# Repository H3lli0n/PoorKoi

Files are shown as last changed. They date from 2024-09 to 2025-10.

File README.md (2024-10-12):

### HLB PoorKoi is a 60% stacked acrylic keyboard

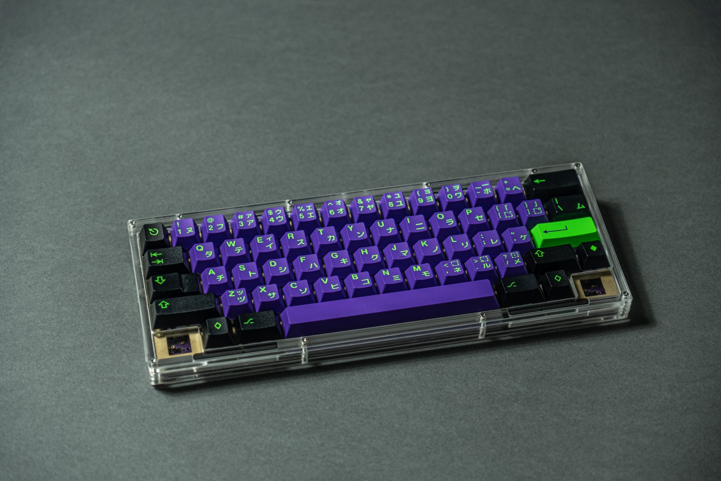
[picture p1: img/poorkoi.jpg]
Prototype


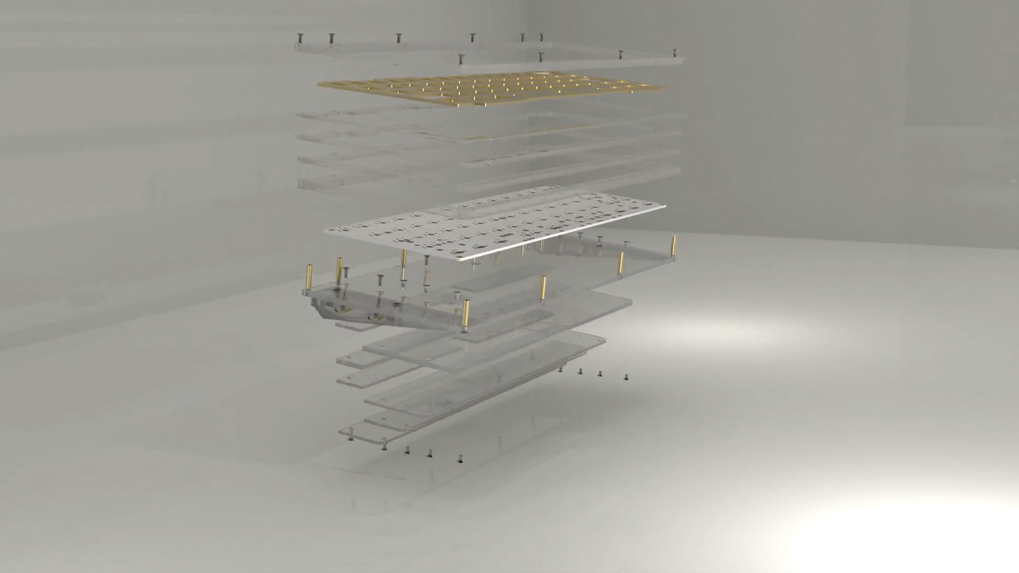
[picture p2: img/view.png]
Stack


# Why PoorKoi

Well it's a funny joke between a poor version of a well known 60% keyboard kit with a kohaku and also a wordplay with _Pourquoi_ a french word meaning _Why_

# Where can I buy one ?

Unfortunately PoorKoi was a private group-buy on Deltakeyco.com from July 1st to July 15th 2024.
At this time we don't share drawings of acrylic layers but plate STEP file is available.

# What can I find here ?

Here you'll find the build guide as well as the firmware for pcb. It's based on 4pplet pcb with a custom look and source code is available to match the open source license.
Firmware is matching our layout as well as options such as:
- Split backspace
- Split left shift
- Iso Enter
- Split spacebar
- WK/WKL/HHKB layout
- RGB underglow
- Capslock LED support

# Layouts

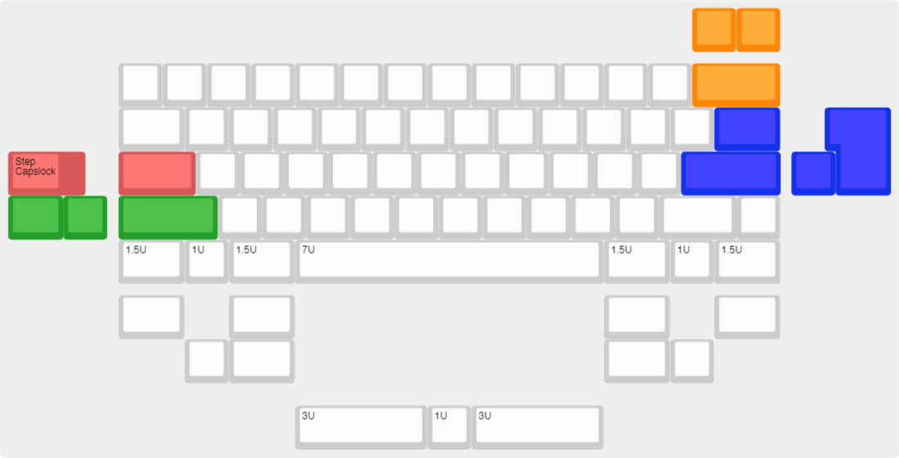
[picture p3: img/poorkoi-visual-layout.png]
Supported_layouts


# Release notes after production

* 2024/10/12 notes about upcoming free fixes [fixes note](notes/october2024/october20241012.md)
* 2024/10/07 listing the issues and upcoming free replacement parts [release note](notes/october2024/october20241007.md)

# Special note / Disclaimer

PCB underglow was not described in the GB and we were keeping it as a secret. After the GB, 5 people requested and extra PCB in purple and this batch was ordered with the same production file. Those 5 pcb arrived before the white ones and everything was fine.

When Deltakeyco received the white PCB we discovered underglow LED were missing. As 5 people would be able to  make pictures with underglow we decided to buy and include the missing LED in the package.

You're free to solder or ask someone to solder. Be advised this process is not so easy as parts are very tiny. Please take time to ask or watch video how to properly solder those components ! 

Ok now you are well aware of the risks, you can follow for example this documentation : [How to Solder SMD / SMT Components](https://www.instructables.com/How-to-Solder-SMD-SMT-Components-With-a-Soldering-/)
On the PCB you will find 16 spots like this one 

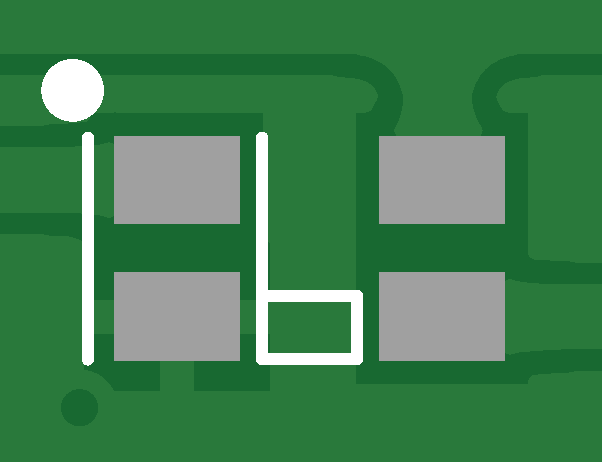
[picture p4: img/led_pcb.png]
PCB led footprint


As you can see there is a dot and vertical line giving you the correct side for the SMD led component. When you flip it the green line must be on the same side as the dot

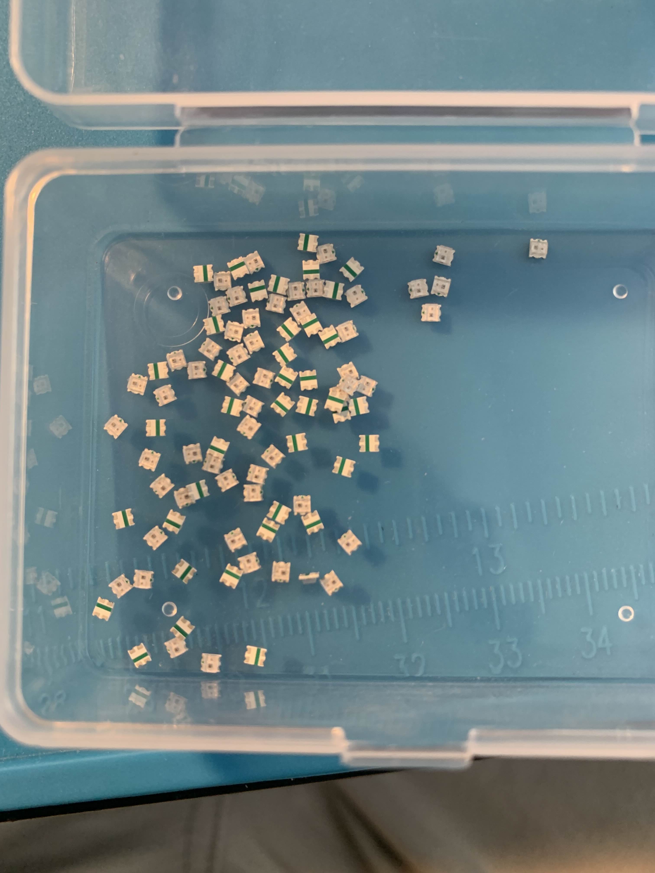
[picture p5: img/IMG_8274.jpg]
SMD


# So what's next ?

Next HLB's project is a TKL made of aluminum with CNC machining. It will be more expensive but others _Poor_ projects will come next.
Follow us on discord for more information here: https://discord.gg/pehBKyyYYs

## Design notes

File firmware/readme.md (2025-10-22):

# Vial Firmware

- This folder contains the latest VIAL firmware

[PoorKoi latest firmware](https://github.com/H3lli0n/vial-qmk/releases?q=poorkoi&expanded=true)

# How-to flash

Simply use the old and well known QMK Toolbox. Use desktop version of VIAL to backup ad restore your layouts.

# Source code

- Source code is available through my fork [here](https://github.com/H3lli0n/vial-qmk/tree/HLB_PoorKoi)
- The reset button on pcb is located here and can be activated with tweezers
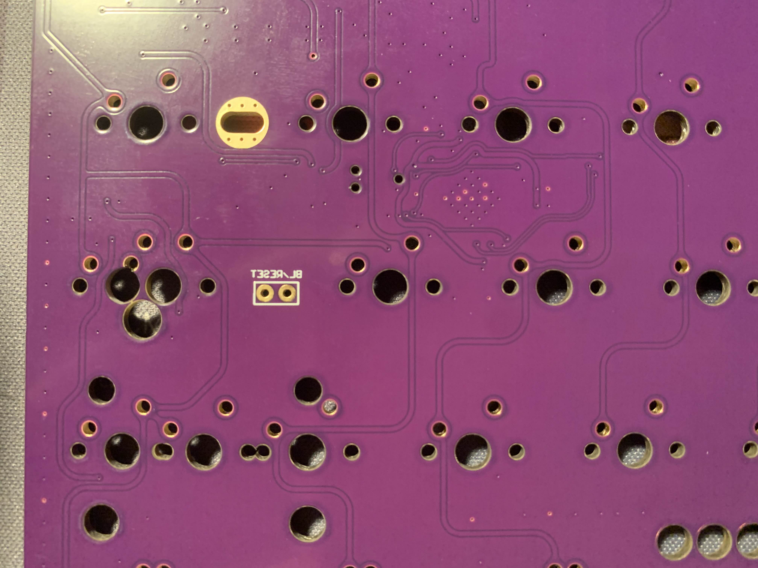
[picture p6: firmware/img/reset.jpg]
Reset


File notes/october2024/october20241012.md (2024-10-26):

# Mise en place du sav

Le sav est en cours de production et est attendu pour la fin du mois.<br>
**Pour rappel, les pièces acryliques et la plate en laiton sont à la charge de HLB et donc gracieusement offertes**.<br>
Nous demandons seulement de regrouper si possible votre SAV avec une autre commande prévue chez DKC ou bien avec un copain de PoorKoi.

Sont donc à votre charge les quelques fournitures de visserie évoquées plus bas.

Concernant les corrections nous avons donc:
* La correction du trou de fixation des pieds
* Diminution du fraisage pour les vis qui maintiennent la daughterboard
* Eléments de remplacement pour la fixation de la daughterboard
* La plate en laiton revision 2 pour la configuration ISO et/ou les personnes ayant des difficultés à insérer les switches  (taille de 14mm x 14mm au lieu de 13,9mm x 13,9mm)
* Un jst avec les fils dans le bon ordre (si il y a eu casse ou impossibilité de changer l'ordre)
* Des patins en feutrine de 1.5mm pour remplacer ceux en matière plastique qui ne sont pas pratiques

# Plate

Si vous décidez de changer de plate, il vous faut de nouveaux gaskets car le poron est difficile à décoller et peut s'arracher. Voici ceux qui vous ont été livrés:
* https://fr.aliexpress.com/item/1005005171752968.html
  * Choisir 90x4x3mm white

A date le produit est out of stock. Je vous indique un lien alternatif mais trop cher :-(
* https://fr.aliexpress.com/item/1005007081069765.html
  * Choisir 90x4x3mm white

Une autre solution est d'acheter ce rouleau multi-usages EVA et de découper vos gaskets dedans
* https://fr.aliexpress.com/item/1005005057632486.html
  * Choisir épaisseur 3mm mais la matière est plus dense que le poron et donc moins compressible. En ce sens je privilégierai donc le 2mm ce qui peut également apporter un peu de flex général.

A noter que le EVA isole mieux que le poron, avec 2mm on a donc une meilleure absorption des ondes et potentiellement du flex. Sous réserve d'expérimentation.

# Fixation de la daughterboard

Pour résoudre les problèmes de la fixation de la daughterboard, je vous propose 3 solutions.
Voici les liens vers les fournitures des solutions:
* https://fr.aliexpress.com/item/1005006049595637.html	
  * Choisir M2 x 3mm
* https://fr.aliexpress.com/item/1005005974779771.html	
  * Choisir M2 x 3mm
* https://fr.aliexpress.com/item/1005003323071003.html	
  * Choisir M2 white

## Scénario 1 : taux de réussite 60%

* Réutiliser la visserie existante
* Utiliser la petite plaque de 2mm en dessous de la daughterboard
* Utiliser les oring pour compenser le 1 à 2mm perdu sur le pas de vis

Voici une illustration
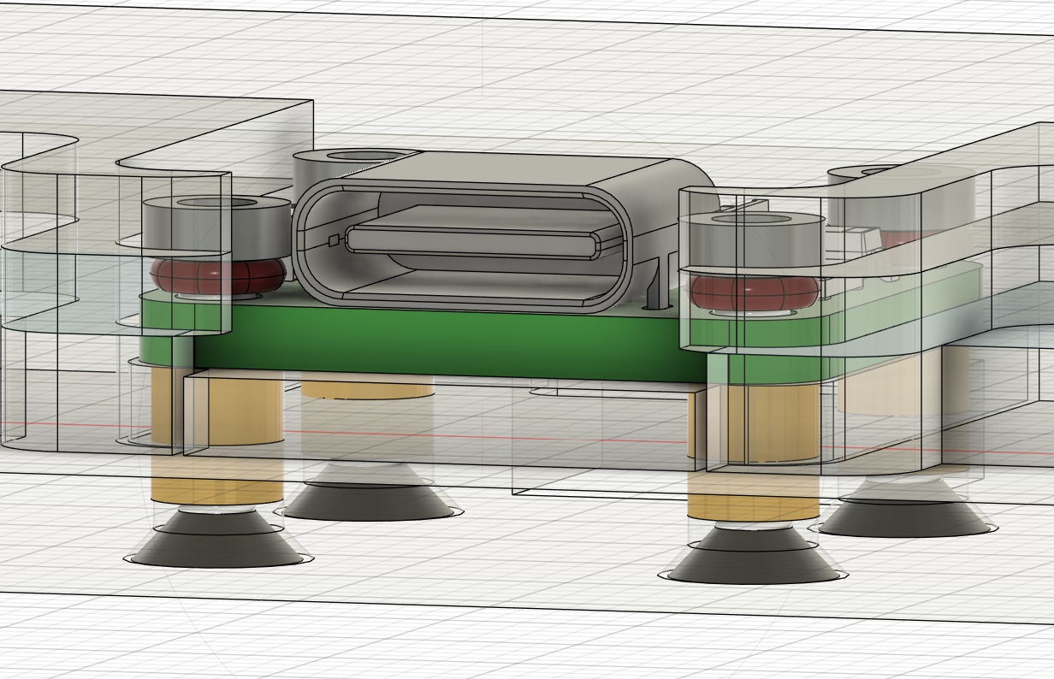
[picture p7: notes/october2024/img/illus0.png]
Scénario 1


## Scénario 2 : taux de réussite 80%
* Utiliser les vis fraisées M2 x 3mm commandées
* Réutiliser les entretoises 4mm
* Utiliser la plaque de 2mm en dessous de la daughterboard

La db ne sera pas plaquée sur le plaque avec les résidus de soudure en dessous, les vis de 3mm sont adaptées et en serrant des 2 côtés la prise de filet sera homogène.

Voici une illustration
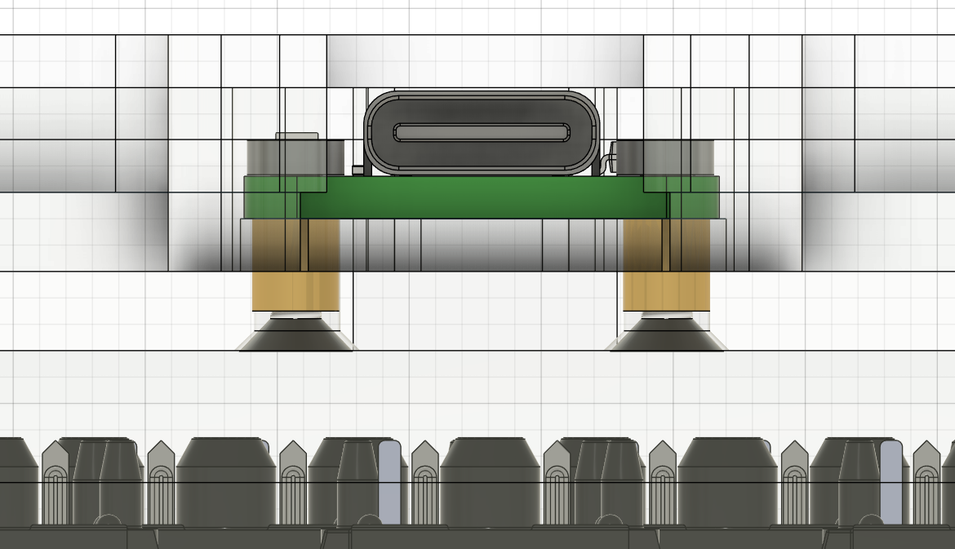
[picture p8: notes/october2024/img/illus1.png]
Scénario 2a

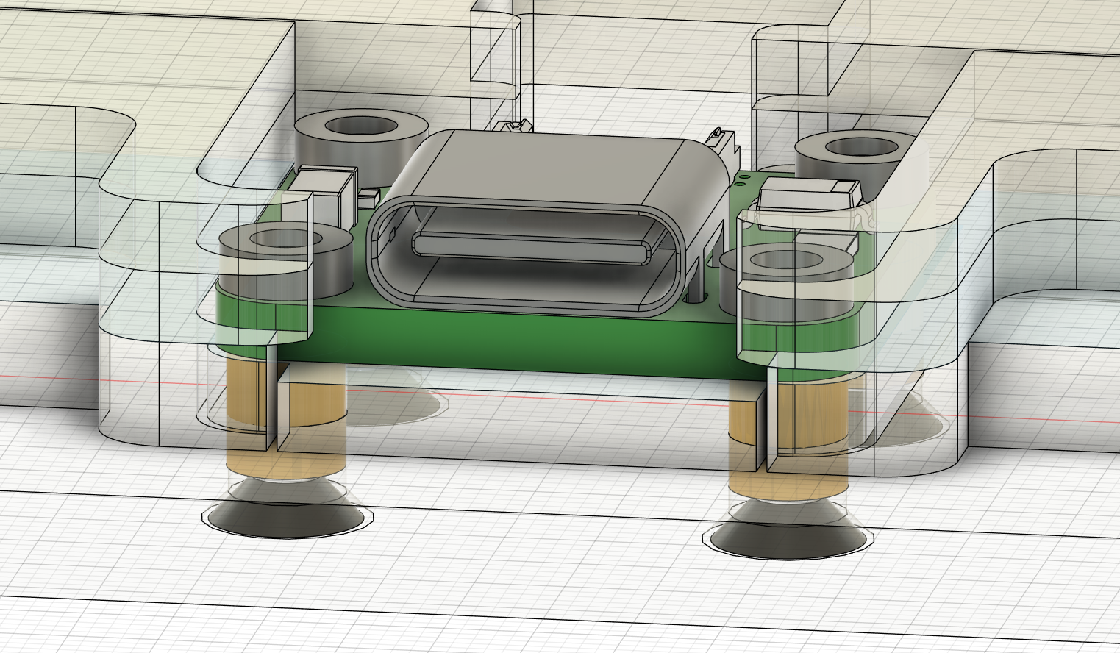
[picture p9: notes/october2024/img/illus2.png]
Scénario 2b


## Scénario 3 : taux de réussite 99% :-)

Ce scénario revient à la configuration du proto. Lors du montage il a été noté que manipuler les vis de 3mm avec une entretoise de 3mm était compliqué et que la prise de filet devait être précise.
Néanmoins la daughterboard était correctement positionnée et ne bouge pas.

Pour reprendre le design original tout en ayant une marge de manoeuvre sur la prise de filet, j'ai donc demander la réalisation d'une plaque de 1mm qui va permettre de combler les écarts.

Ce scénario offre aussi le meilleur espacement entre le haut du port usb et la plaque couvrante, nous aurions dû conserver ce design.

* Utiliser les entretoises M2 x 3mm
* Utiliser les vis fraisées M2 x 3mm
* Utilliser la plaque de 1mm sous la daughterboard si nécessaire ou les oring

Voici une illustration
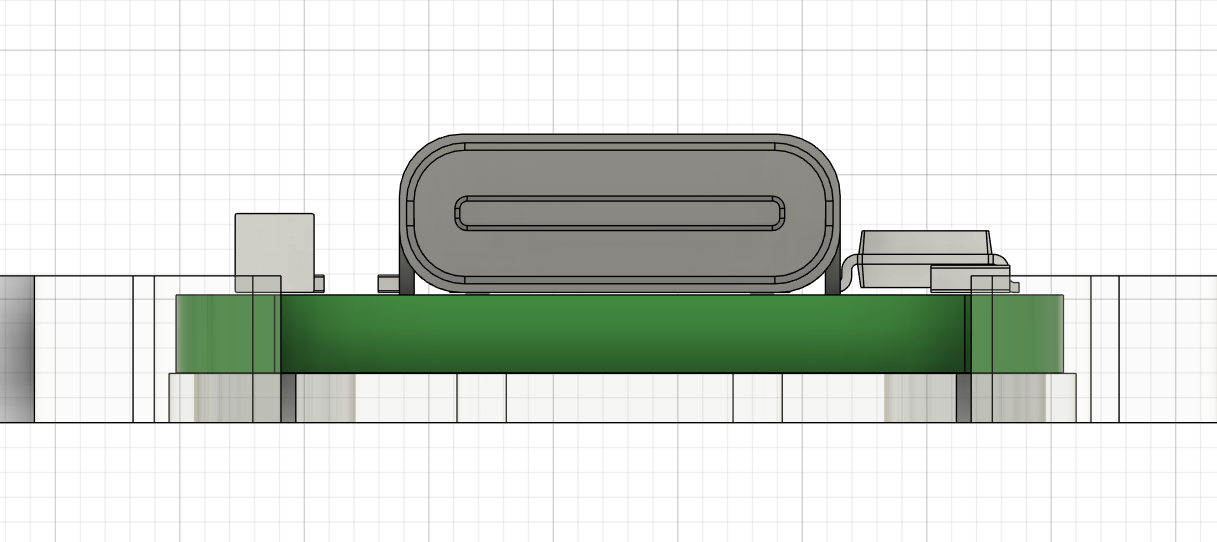
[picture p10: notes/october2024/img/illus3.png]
Scénario 3a

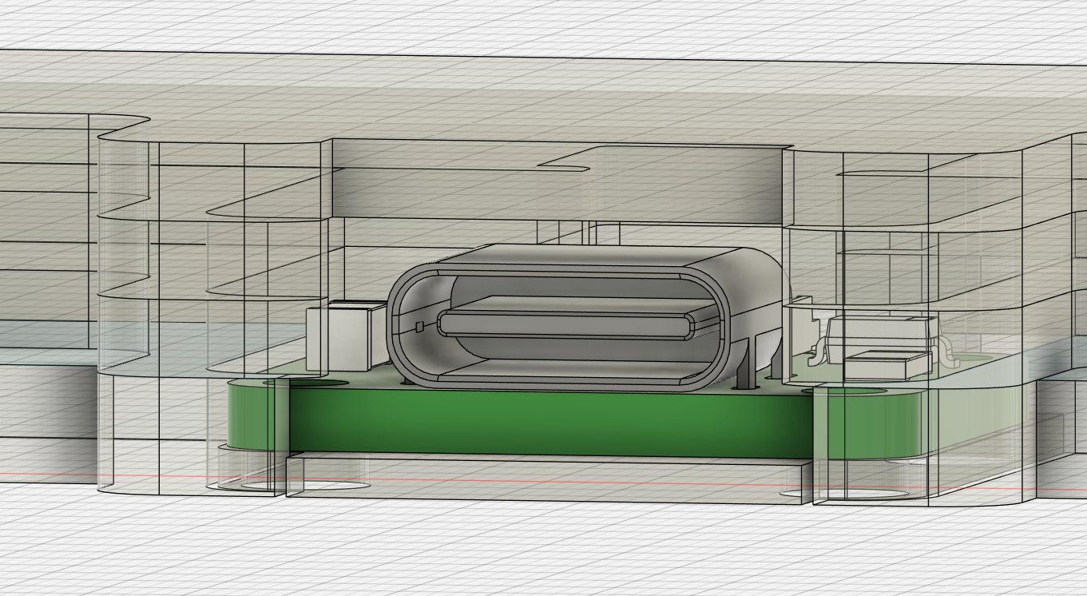
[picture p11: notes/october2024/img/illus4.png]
Scénario 3b


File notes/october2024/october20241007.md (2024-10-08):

# Note sur la production au 7/10/2024

Suite aux livraisons et build du PoorKoi, des problèmes ont été rencontrés à différents niveaux. HLB est désolé de la situation, nous ne pensions pas avoir autant de soucis sur la fin de production.

Tout d'abord je vous informe que nous avons pris l'ensemble des problèmes sérieusement et assumons le SAV. Ainsi, nous avons maintenant la vision d'ensemble des soucis et lançons la mise en production dès que possible du SAV (nous sortons d'une période de vacances en Chine il y a donc du délais).

## Fixation des pieds

Un trou de fixation n'est pas axé avec la plaque principale possédant le Koi:
* modification suite au prototype
* le dessin a été mis à jour
* la plaque va être commandée pour 30 unités

## Port USB

* modification suite au prototype pour éviter de manipuler de la visserie 3mm
* effet de bord sur l'espacement avec le port usb
* erreur humaine lors des vérifications
* retour arrière sur la fixation de la daughterboard sur la base du prototype

### Avant

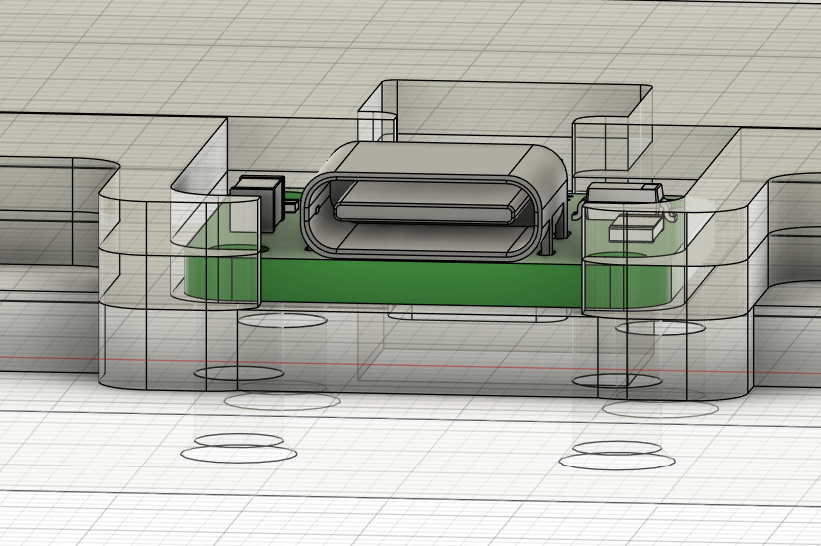
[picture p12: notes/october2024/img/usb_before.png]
Avant


### Après 

Fix en cours (peut changer)

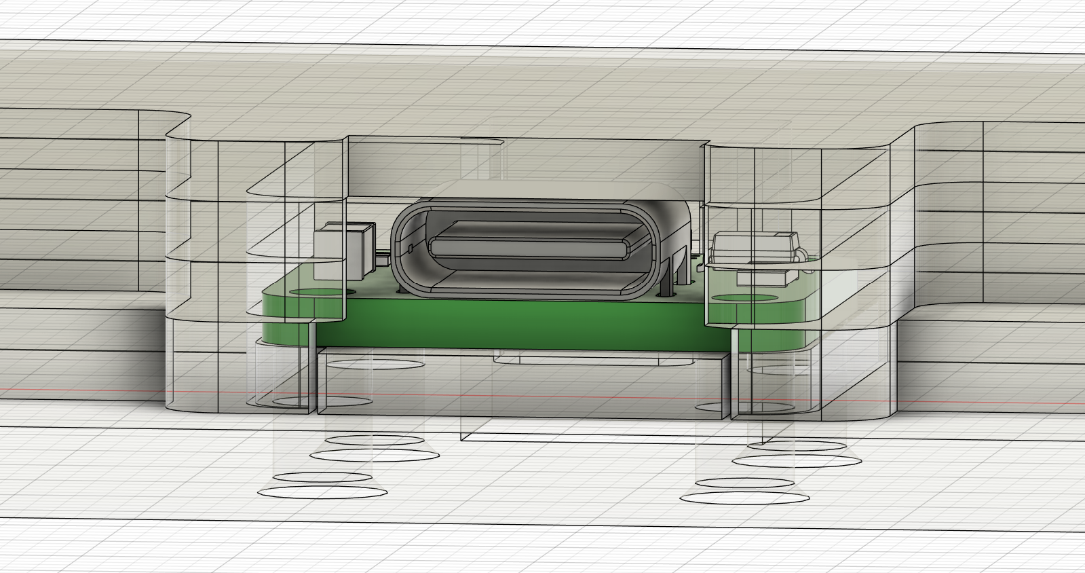
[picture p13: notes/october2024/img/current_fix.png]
Après


note: une communication sera réalisée sur la visserie à utiliser

## JST to molex

Comme expliqué sur le discord, la connexion initiale était JST-JST mais suite à une erreur de fichier lors de la production chez JLC, nous avons livrer des daughterboard JST-Molex et avons par conséquent commandé les câbles nécessaires avec le schéma technique officiel.

Les câbles sont arrivés avec un connecteur inversé et sommes en conversation avec l'entreprise, pour qui la production reflète le dessin; ce qui est faux.
A ce jour je suis toujours en «litige» avec eux mais vous pouvez inverser vous-même les fils (venez sur le discord pour un tuto).

=> en attente réponse entreprise

## Plate pour le ISO

Une erreur est apparue chez les utilisateurs ISO, une découpe est manquante pour le switch situé à côté du Enter ISO.
* erreur humaine lors de la mise en forme de la plate
* une plate de remplacement va être commandée pour les 30 unités et fournie dans le carton
* nous allong également mettre les emplacements de switchs en 14mm et non en 13.9mm suite à des remontées sur des switchs trop serrés

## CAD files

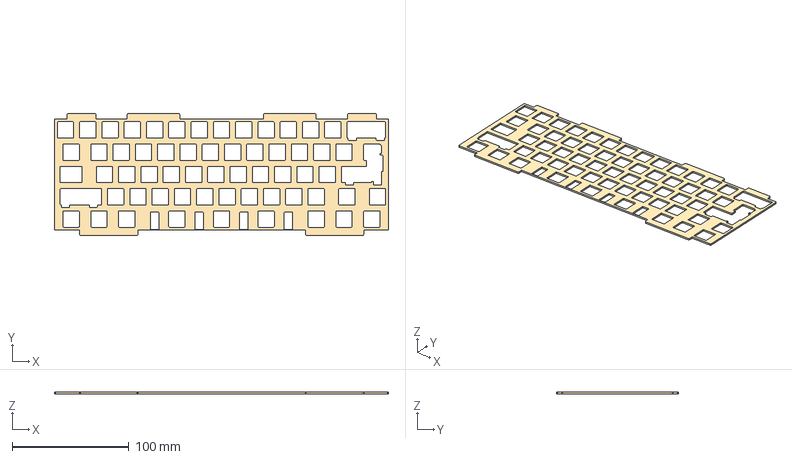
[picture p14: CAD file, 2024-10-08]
production_files/plate_rev3.step
285.6 x 104.3 x 1.50 mm

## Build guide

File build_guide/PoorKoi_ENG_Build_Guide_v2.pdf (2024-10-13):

# PoorKoi

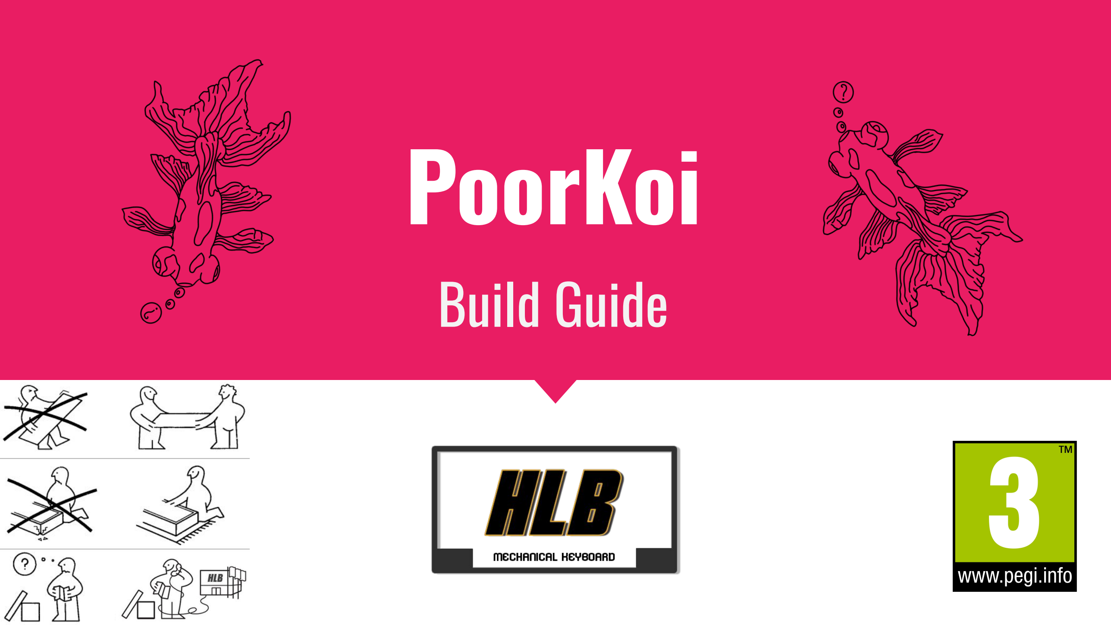
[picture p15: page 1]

# Build Guide

# Step 0 : kit content

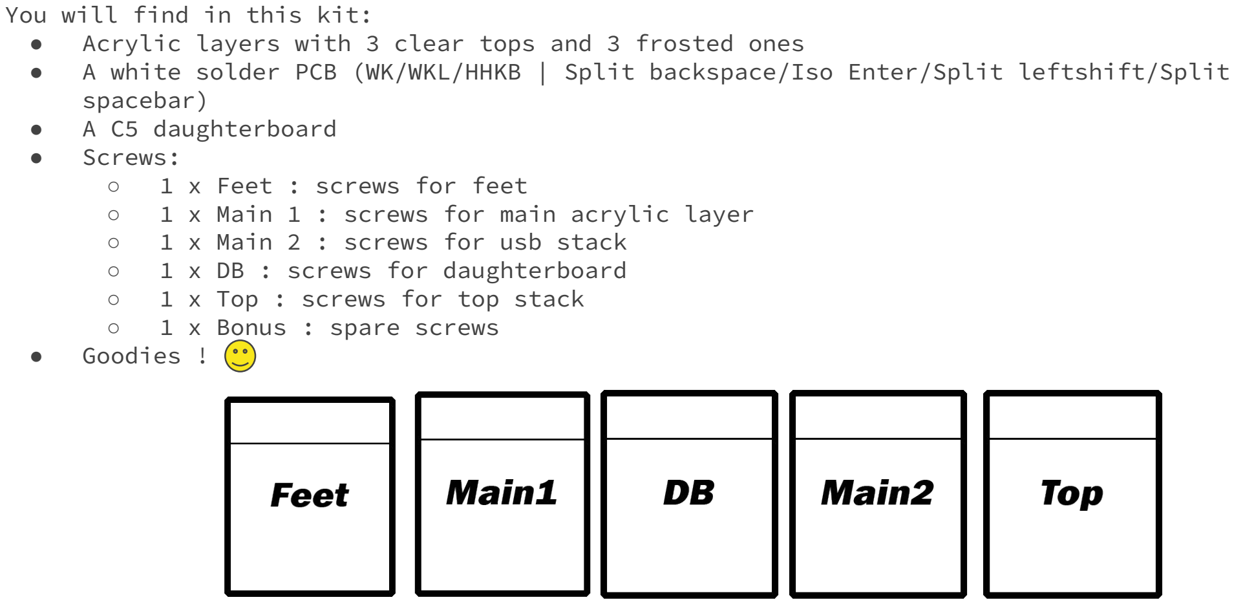
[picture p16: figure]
You will find in this kit:; spacebar) ● A C5 daughterboard ● Screws: ○ 1 x Feet : screws for feet; ○ 1 x Main 2 : screws for usb stack ○ 1 x DB : screws for daughterboard ○ 1 x Top : screws for top stack ○ 1 x Bonus : spare screws ● Goodies !

- Acrylic layers with 3 clear tops and 3 frosted ones
- A white solder PCB (WK/WKL/HHKB | Split backspace/Iso Enter/Split leftshift/Split
- 1 x Main 1 : screws for main acrylic layer

# Step 0 : content

Kit is full of surprises with 24 simple configurations mixing frosted and clear parts. In white all the parts available in both variants.

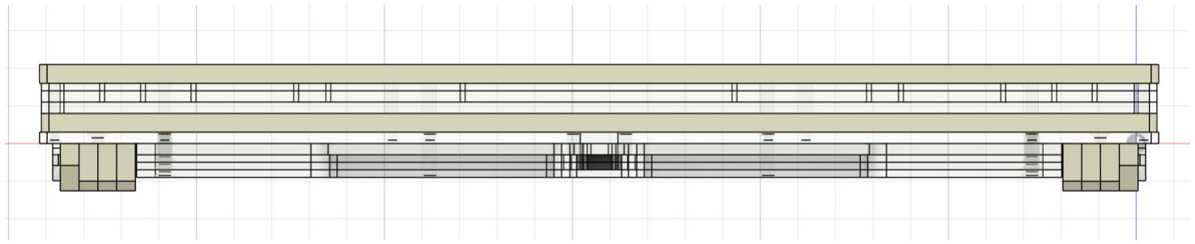
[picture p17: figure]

-tops
-5mm acrylic layer on top of Koi’s one -5mm pieces of feet

# Step 1 : qmk toolbox installation

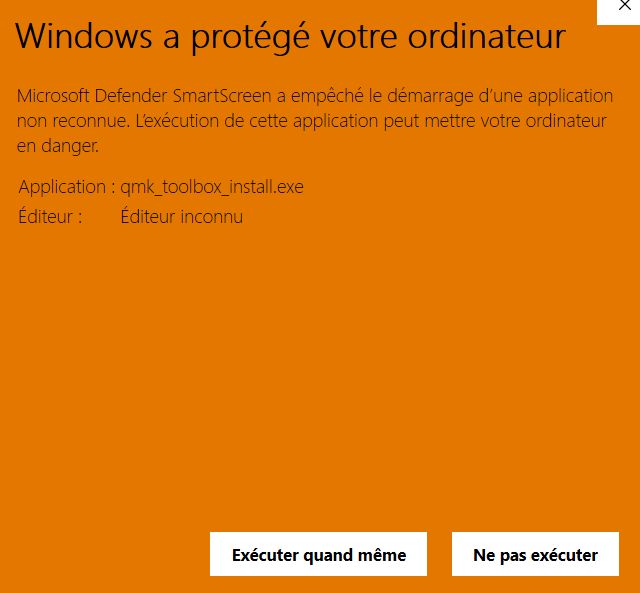
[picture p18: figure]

- PCB is empty of firmware, you will learn if not how to flash your PCB. Easy step no worries !
- Download QMK Toolbox here: https://github.com/qmk/qmk_toolbox/releases/download/0.3.3/qmk_toolbox_install.exe (https://github.com/qmk/qmk_toolbox/releases/download/0.3.3/qmk_toolbox_install.exe) (latest version at the time of writing)
- You can trust the installer, the warning is related to missing certificate
- Once installed, please launch as administrator
- Click on Tools\Install drivers and wait the console closing by itself

# Step 1 : firmware flashing

1

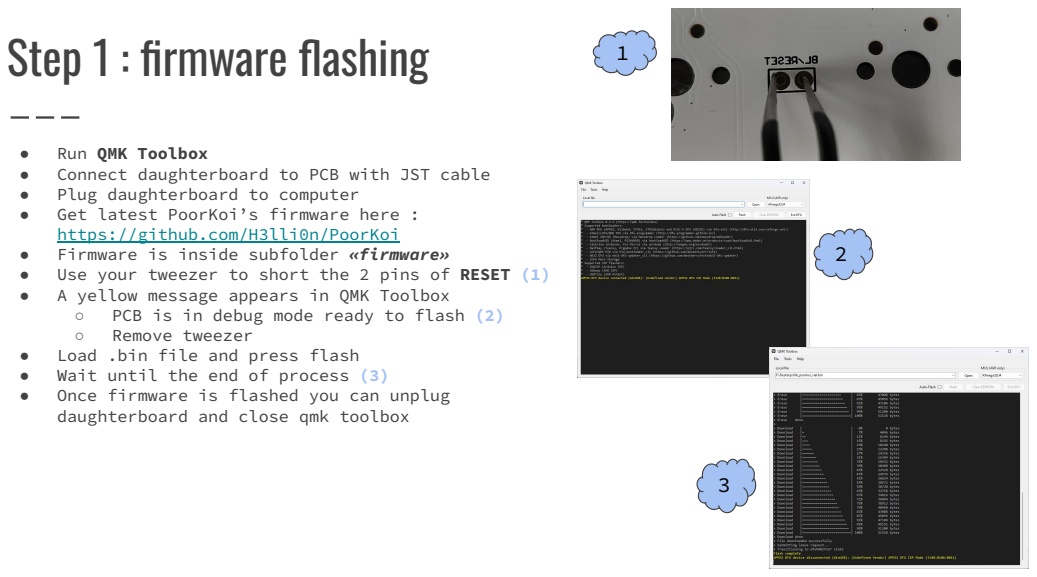
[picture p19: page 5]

● Run QMK Toolbox
● Connect daughterboard to PCB with JST cable
● Plug daughterboard to computer
● Get latest PoorKoi’s firmware here :
https://github.com/H3lli0n/PoorKoi
● Firmware is inside subfolder «firmware»
● Use your tweezer to short the 2 pins of RESET (1)
● A yellow message appears in QMK Toolbox
○ PCB is in debug mode ready to flash (2)
○ Remove tweezer
● Load .bin file and press flash
● Wait until the end of process (3)
● Once firmware is flashed you can unplug
daughterboard and close qmk toolbox

# Step 2 : check PCB

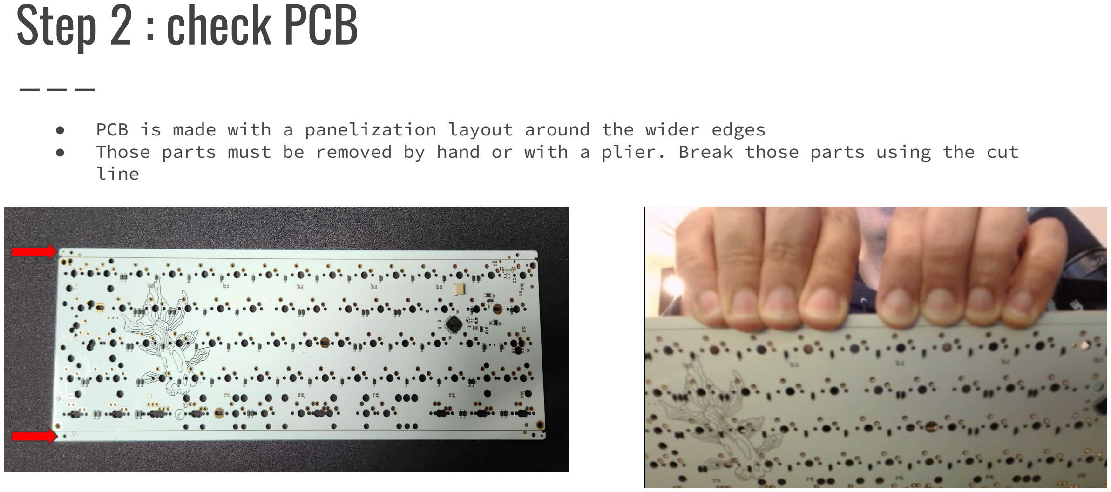
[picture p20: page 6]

- PCB is made with a panelization layout around the wider edges
- Those parts must be removed by hand or with a plier. Break those parts using the cut line

# Step 2 : check PCB

- | To test PCB we will use | https://config.qmk.fm/#/test | because VIAL requires to unlock
PCB and without switches it’s a dual tweezers process
- Plug daughterboard
- User your tweezer to test each switch contact holes. Everyone must answer except MO(1) located at the right of right shift
- Once PCB is checked you’re free to solder or mill-max your PCB
- PCB supports underglow RGB but due to some issue during order, you have to solder the led included in the kit. Please read carefully the disclaimer on the main git
| repo webpage.
- Lube and test your stabilizers
- Insert switches on the plate and clip on PCB
- PCB supports caps lock LED think about it before soldering !
- Solder your switches if required

# Step 3 : feet

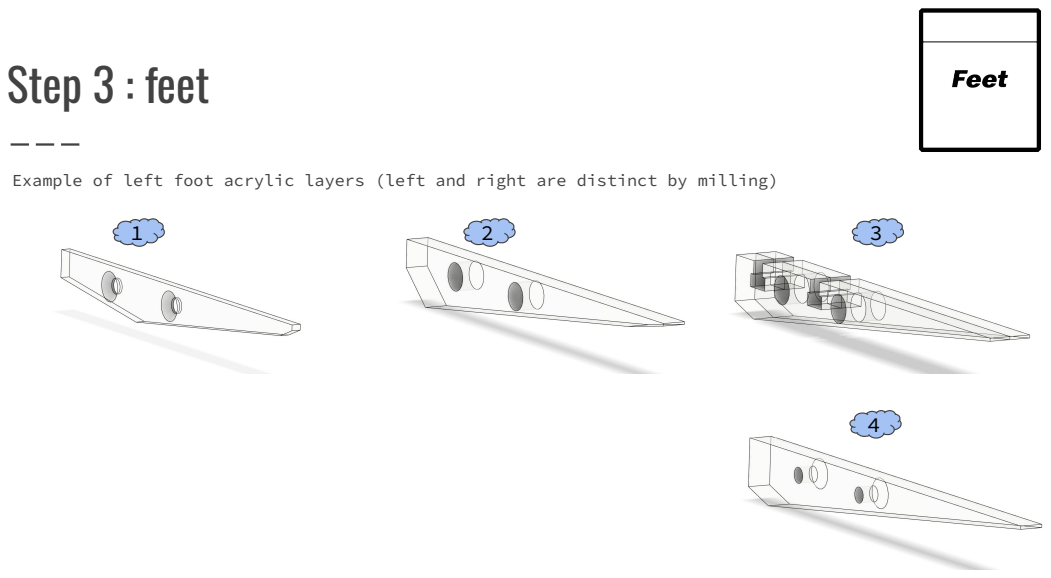
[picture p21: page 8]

Example of left foot acrylic layers (left and right are distinct by milling)

# Step 3 : feet

## Insert

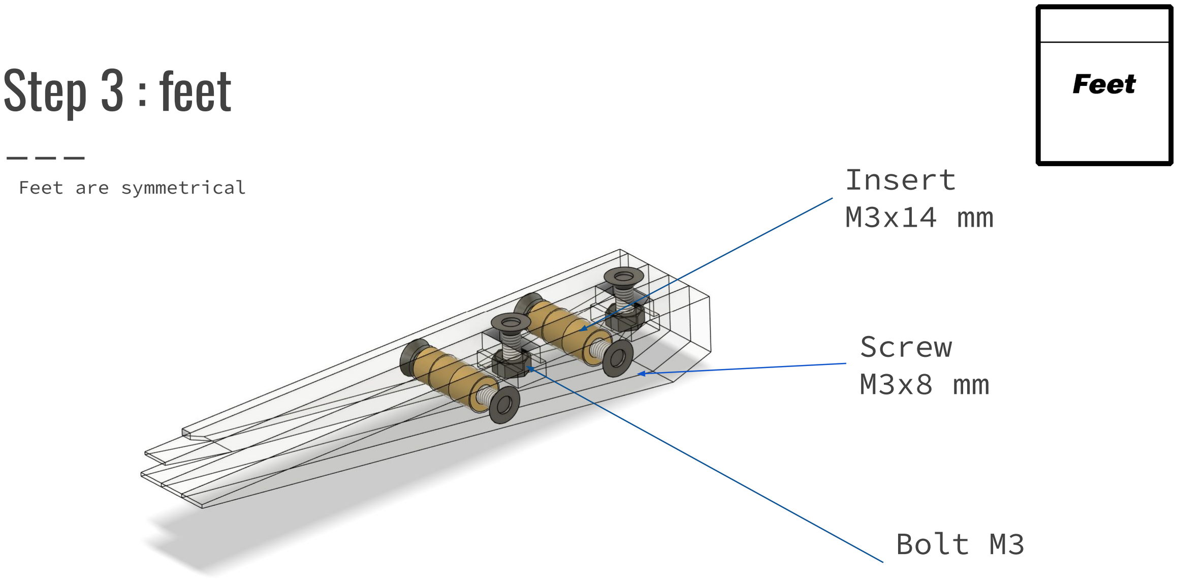
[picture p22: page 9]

## M3x14 mm

## Screw M3x8 mm

## Bolt M3

Feet are symmetrical

# Step 3 : feet

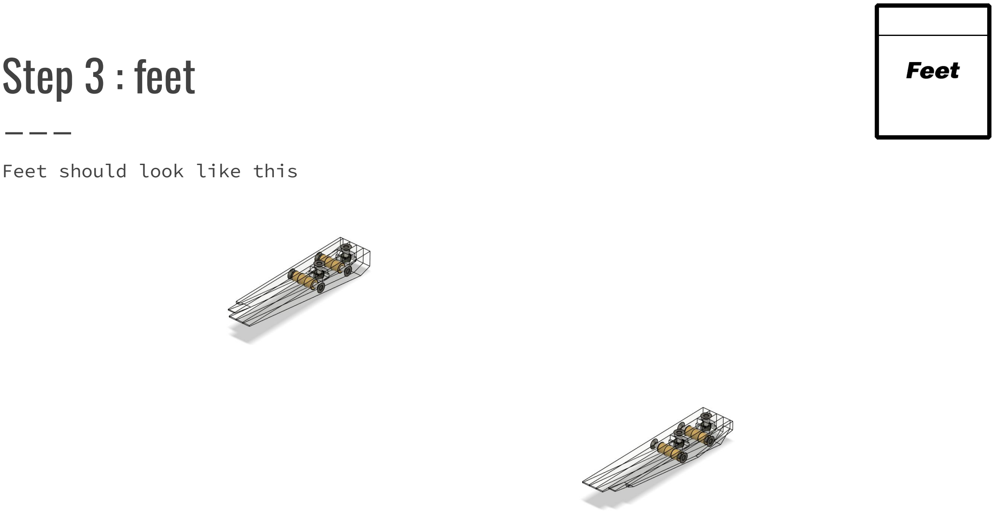
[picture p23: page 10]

Feet should look like this

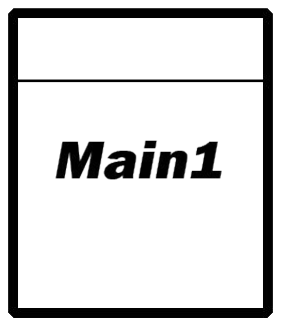
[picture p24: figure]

# Step 4 : bottom stack

- Use Chicago screws head down
- Put the main acrylic layer with koi fish
- Use picture on next page
- Put the other 3 acrylic layers to match next picture

# Step 4 : bottom stack

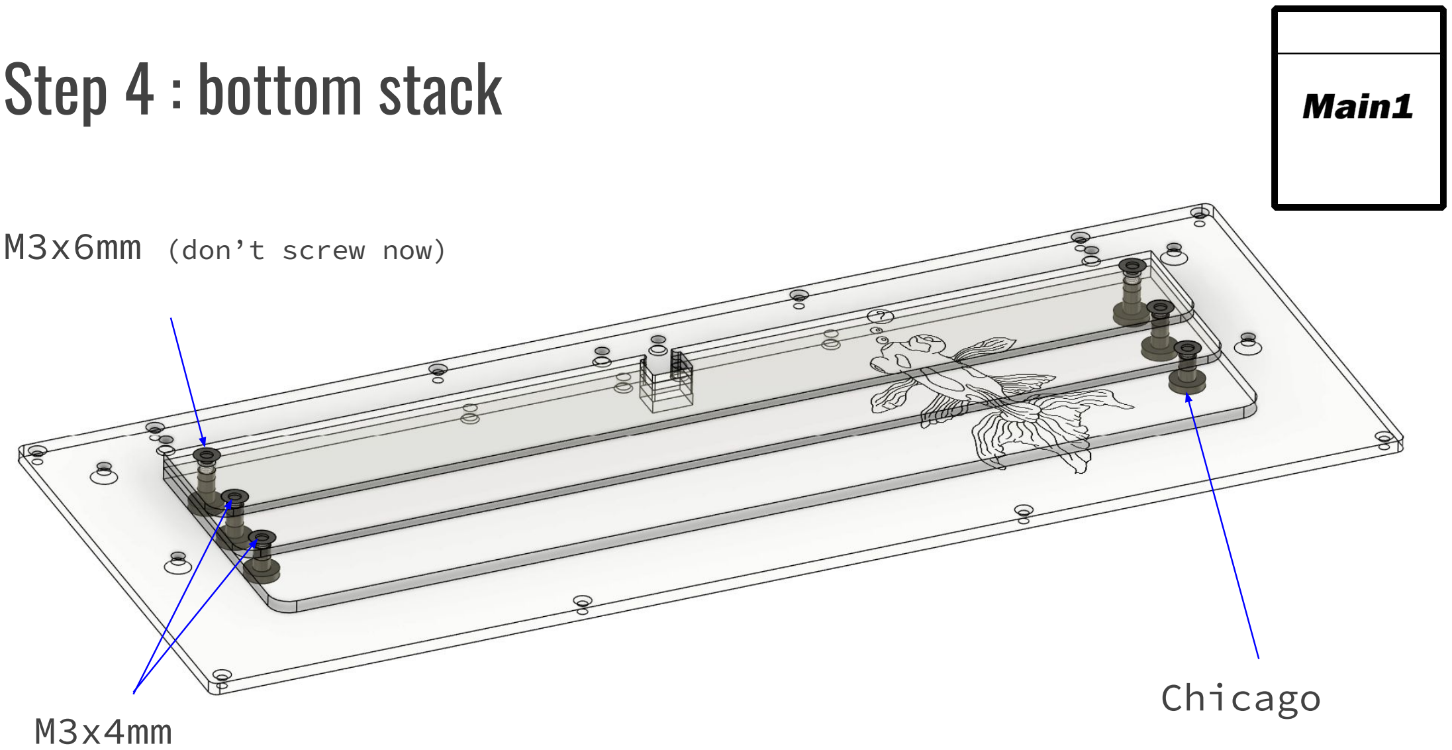
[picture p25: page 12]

## Chicago

M3x6mm (don’t screw now)

## M3x4mm

# Step 4 : bottom stack

- Plug JST cable to daughterboard
- Insert JST through the main acrylic layer

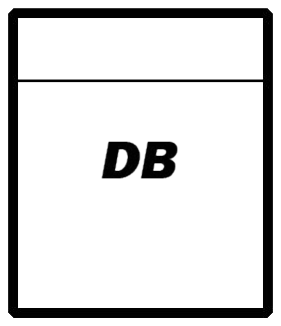
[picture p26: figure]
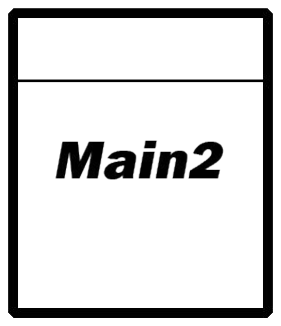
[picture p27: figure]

- Setup countersunk M2 screws and insert and put them on table, screw head down. Insert acrylic layers
- Use M2x3mm screws to secure daughterboard
- Stack halves acrylic layers around the daughterboard and final layer as shown on next picture
- Screw everything to secure bottom stack

# Step 4 : assembler la stack

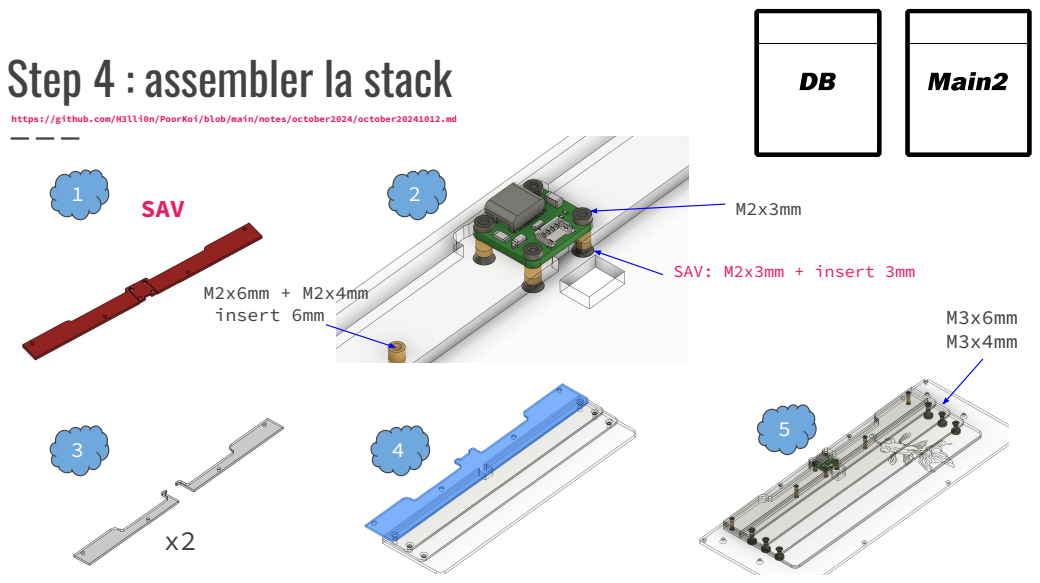
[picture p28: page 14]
SAV; SAV: M2x3mm + insert 3mm; insert 6mm

https://github.com/H3lli0n/PoorKoi/blob/main/notes/october2024/october20241012.md

# Step 5 : feet assembly

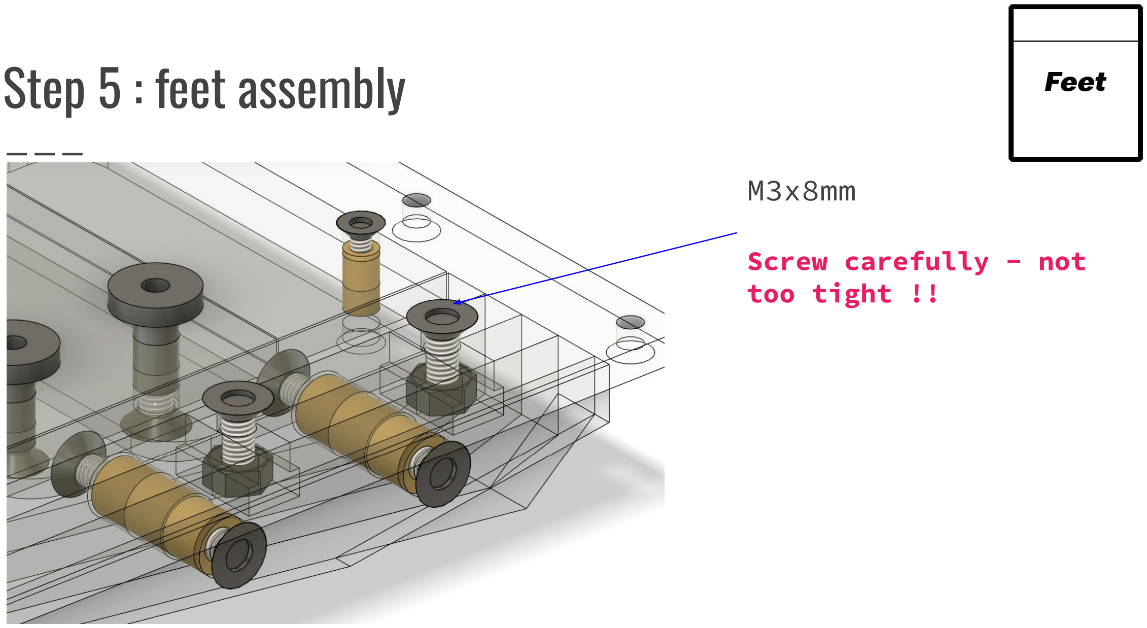
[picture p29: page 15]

## M3x8mm

## Screw carefully - not too tight !!

# Step 6 : gaskets

## Gaskets sizes are :

## - Top : 25 mm / 45 mm / 45 mm / 25 mm - Bottom : 50mm / 50 mm

## Just install gaskets on plate on both sides

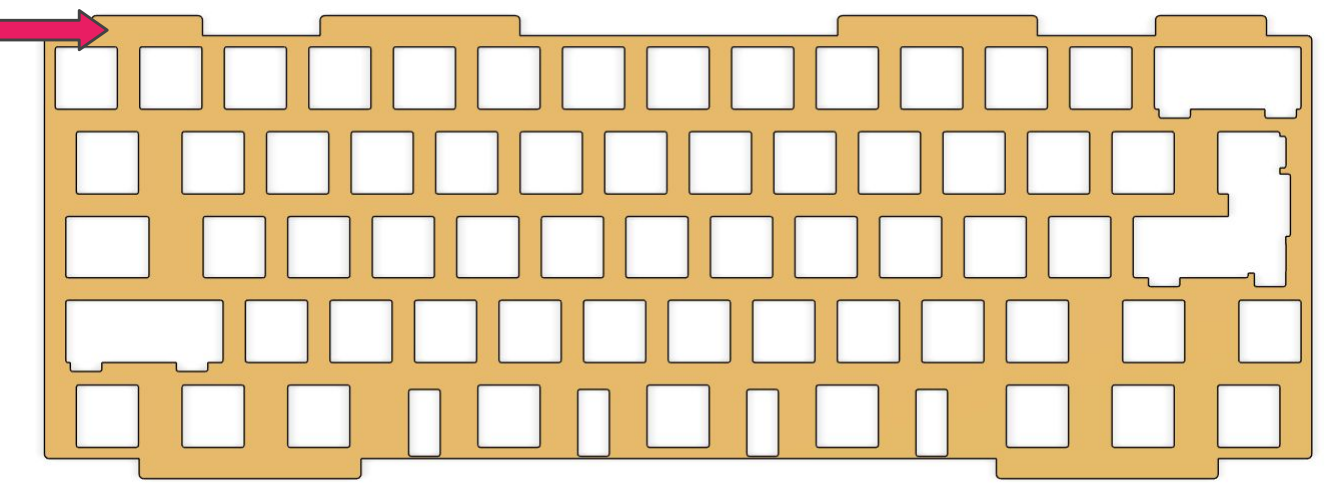
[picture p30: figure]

zone de gasket

## SAV

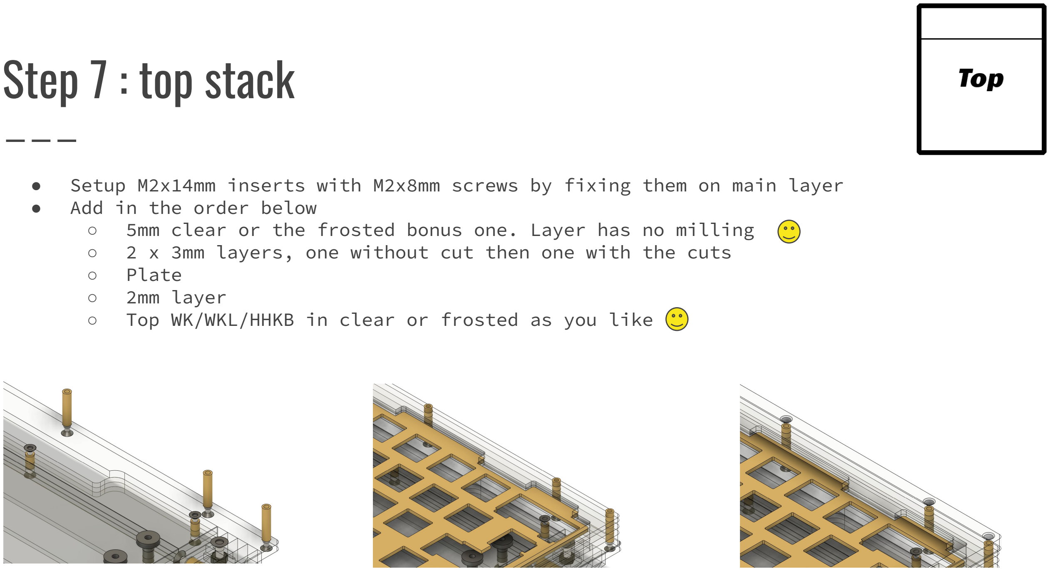
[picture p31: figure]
Step 7 : top stack; ● Add in the order below; ○ Plate ○ 2mm layer

- Setup M2x14mm inserts with M2x8mm screws by fixing them on main layer
- 5mm clear or the frosted bonus one. Layer has no milling
- 2 x 3mm layers, one without cut then one with the cuts
- Top WK/WKL/HHKB in clear or frosted as you like

# Step 7 : top stack

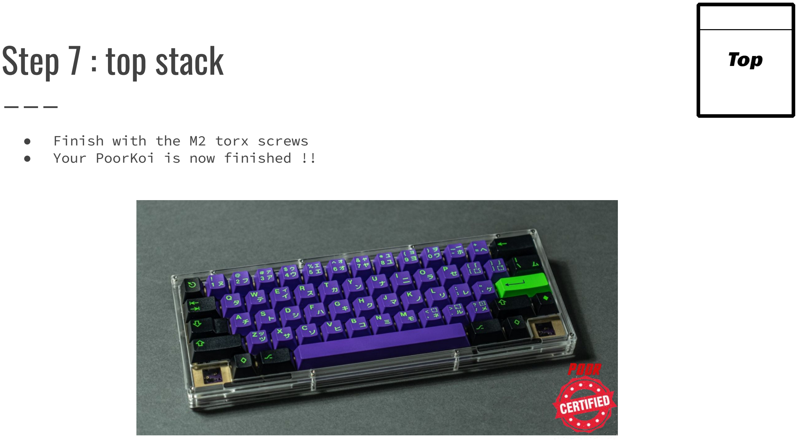
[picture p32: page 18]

- Finish with the M2 torx screws
- Your PoorKoi is now finished !!

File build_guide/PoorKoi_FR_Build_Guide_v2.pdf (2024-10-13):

# PoorKoi


# Build Guide

# Step 0 : contenu du kit

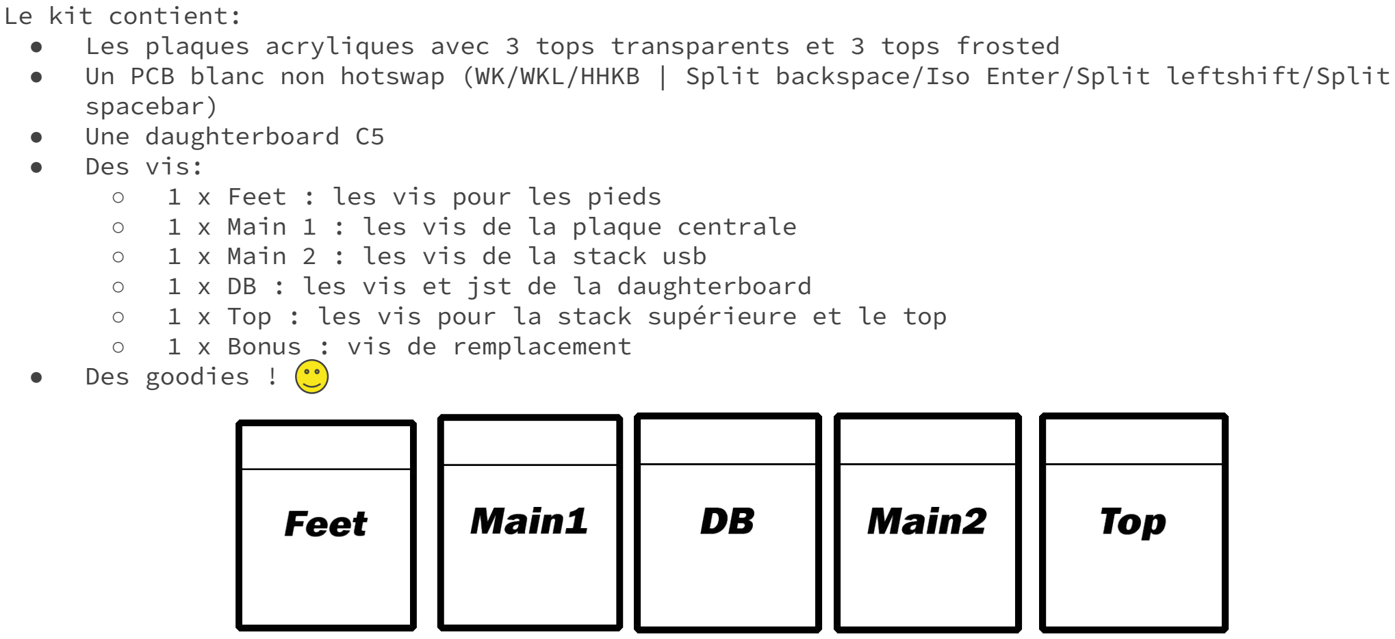
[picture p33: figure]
Le kit contient:; spacebar) ● Une daughterboard C5 ● Des vis: ○ 1 x Feet : les vis pour les pieds; ○ 1 x Main 2 : les vis de la stack usb; ○ 1 x Bonus : vis de remplacement ● Des goodies !

- Les plaques acryliques avec 3 tops transparents et 3 tops frosted
- Un PCB blanc non hotswap (WK/WKL/HHKB | Split backspace/Iso Enter/Split leftshift/Split
- 1 x Main 1 : les vis de la plaque centrale
- 1 x DB : les vis et jst de la daughterboard
- 1 x Top : les vis pour la stack supérieure et le top

# Step 0 : contenu du kit

Le kit contient également des surprises, il y a 24 configurations simples possibles en mixant frosted et clear. Voici en blanc-beige les éléments disponibles dans les deux


-les tops
-la plaque de 5mm au dessus de celle avec le Koi -les pièces de 5mm au niveau des pieds

# Step 1 : installation de qmk toolbox


- Le PCB ne possède pas de firmware, il faut donc l’installer ce qui vous permet également de vous familiariser avec la procédure
- Téléchargez QMK Toolbox ici : https://github.com/qmk/qmk_toolbox/releases/download/0.3.3/qmk_toolbox_install.exe (https://github.com/qmk/qmk_toolbox/releases/download/0.3.3/qmk_toolbox_install.exe) (version la plus à jour)
- Faire exécuter quand même, le message est lié à la non signature de l'installateur
- Poursuivre l’installation et lancer l’outil en administrateur
- Cliquez sur Tools\Install drivers et attendre que la fenêtre de la console se ferme

1

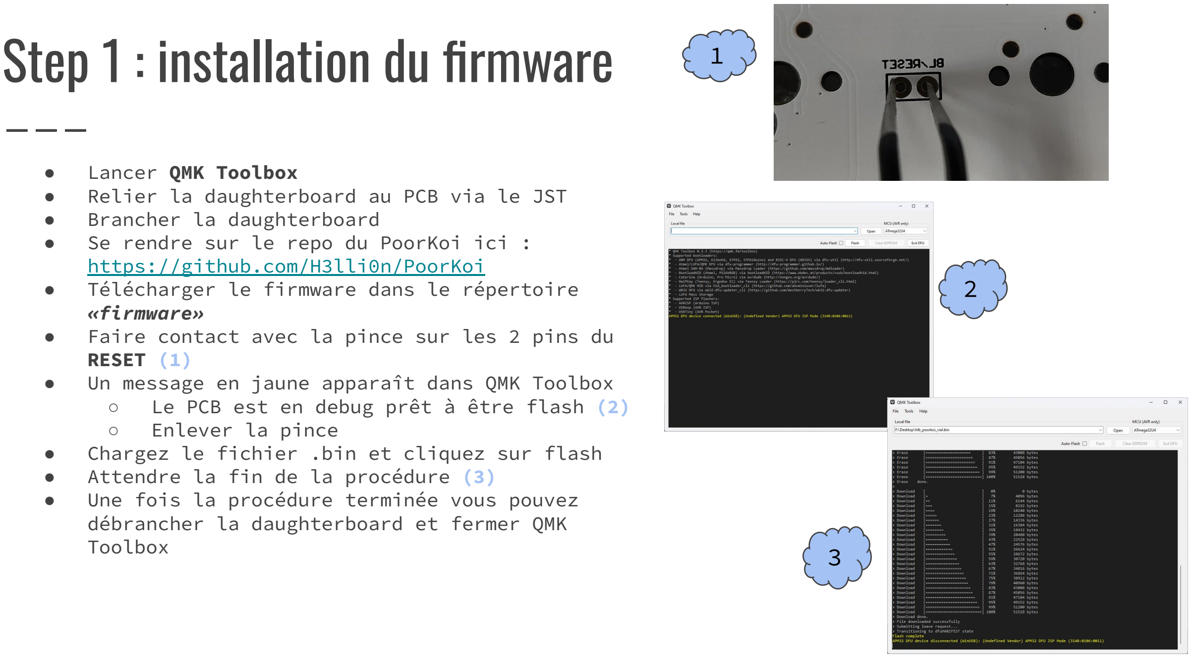
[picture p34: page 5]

Step 1 : installation du firmware ● | Lancer QMK Toolbox ● | Relier la daughterboard au PCB via le JST ● | Brancher la daughterboard ● | Se rendre sur le repo du PoorKoi ici :

https://github.com/H3lli0n/PoorKoi
- Télécharger le firmware dans le répertoire «firmware»
- Faire contact avec la pince sur les 2 pins du RESET (1)
- | Un message en jaune apparaît dans QMK Toolbox ○ | Le PCB est en debug prêt à être flash (2) ○ | Enlever la pince ● | Chargez le fichier .bin et cliquez sur flash ● | Attendre la fin de la procédure (3) ● | Une fois la procédure terminée vous pouvez

débrancher la daughterboard et fermer QMK Toolbox

2

3

# Step 2 : vérification du PCB

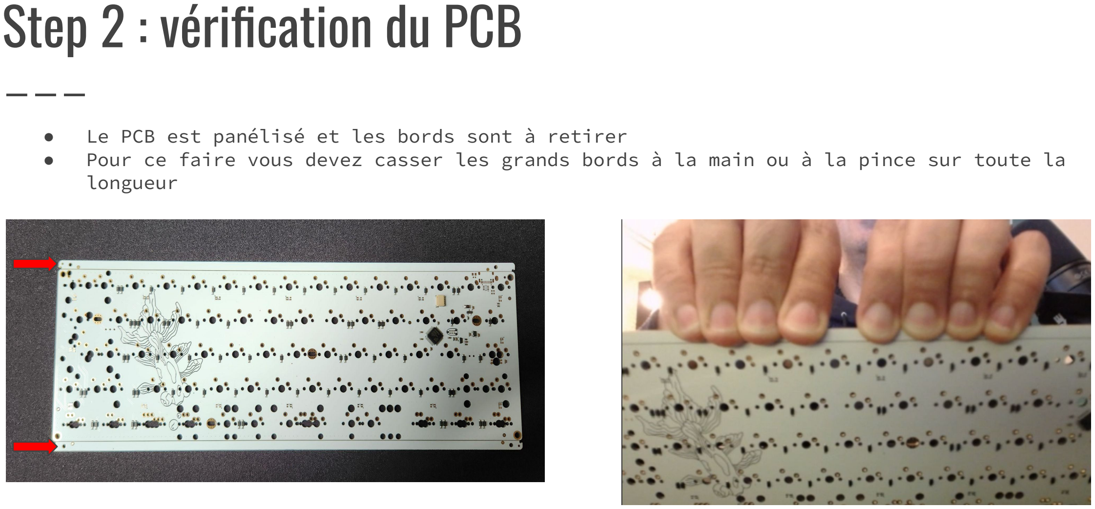
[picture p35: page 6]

- Le PCB est panélisé et les bords sont à retirer
- Pour ce faire vous devez casser les grands bords à la main ou à la pince sur toute la longueur

# Step 2 : vérification du PCB

- | Pour tester le PCB nous utiliserons | https://config.qmk.fm/#/test | car VIAL nécessite de
unlock le PCB et sans switch il faut 2 pinces pour le faire
- Brancher la daughterboard
- Testez à la pince les touches, elles doivent toutes répondre sauf la touche MO(1)
| située à droite du right shift
- Une fois le PCB fonctionnel libre à vous de mill-max ou de souder directement les
| switch
- Le PCB est compatible RGB underglow mais suite à une erreur lors de la commande les leds sont à souder soi-même. Lisez bien le disclaimer sur la page principale
| du repo git
- Préparer les stabilisateurs puis les mettre en place
- Installer les switchs et la plate
- Le PCB supporte la LED de capslock, pensez-y avant de tout souder !
- Souder si nécessaire les switchs

# Step 3 : assembler les pieds

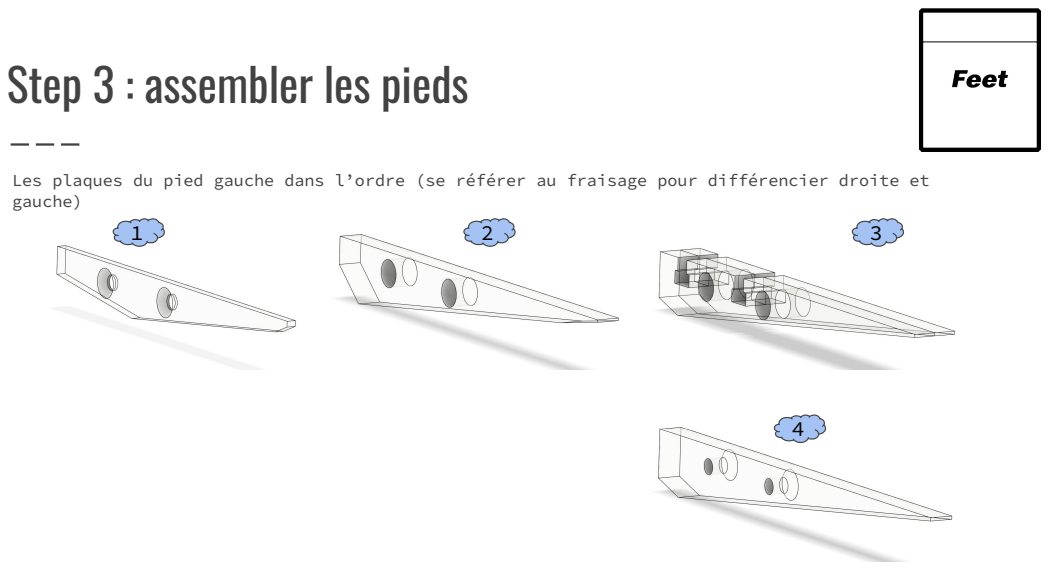
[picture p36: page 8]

Les plaques du pied gauche dans l’ordre (se référer au fraisage pour différencier droite et
gauche)

# Step 3 : assembler les pieds

## Insert

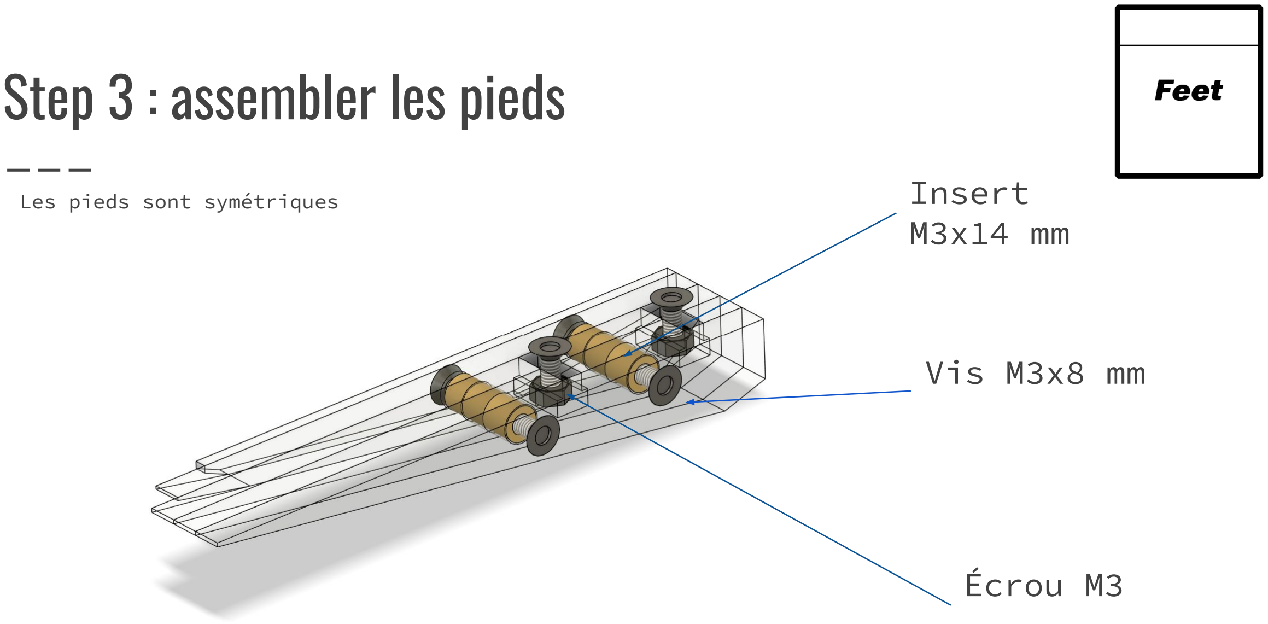
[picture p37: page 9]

## M3x14 mm

## Vis M3x8 mm

## Écrou M3

Les pieds sont symétriques

# Step 3 : assembler les pieds

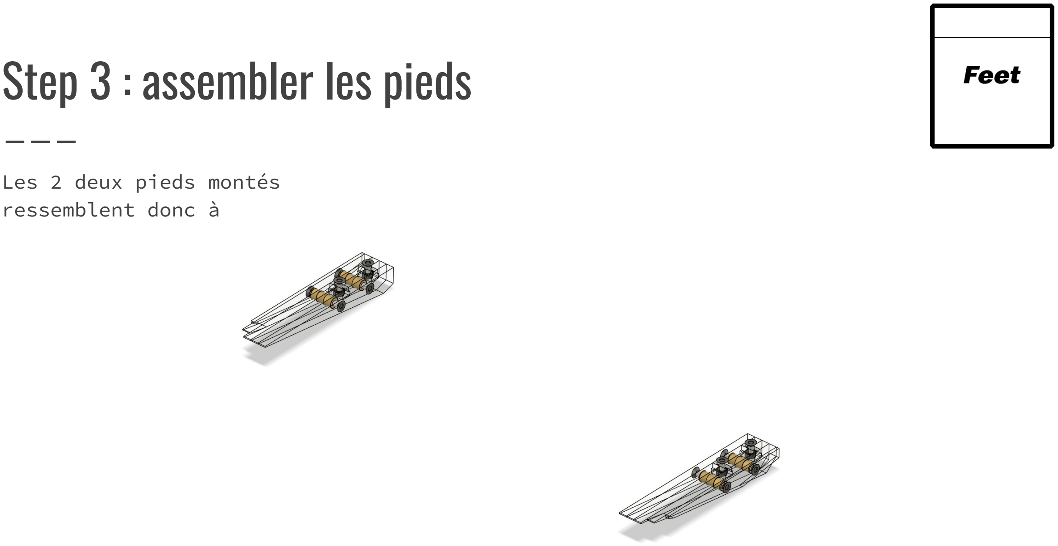
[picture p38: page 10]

Les 2 deux pieds montés
ressemblent donc à


# Step 4 : assembler la stack

- Positionner les vis Chicago tête en bas
- Mettre la plaque «plateforme» contenant le poisson gravé
- Attention au sens voir image après
- Superposer les 3 plaques de la stack comme sur le visuel

# Step 4 : assembler la stack

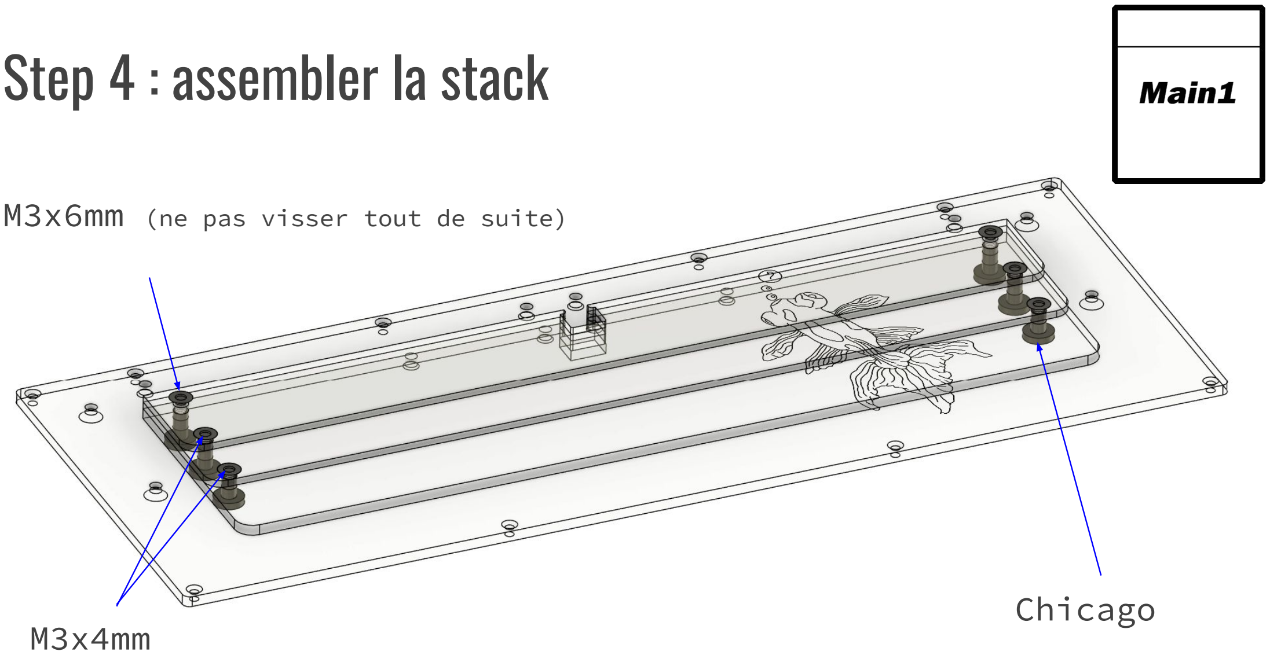
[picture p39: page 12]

## Chicago

M3x6mm (ne pas visser tout de suite)

## M3x4mm

# Step 4 : assembler la stack

- Mettre le JST sur la daughter board
- Faire passer le JST dans le trou de la plaque «plateforme»


- Préparer les vis et inserts M2 pour fixer les stacks et les positionner tête de vis en bas
- Visser la daughter board
- Positionner les petites plaques ainsi que la plaque finale recouvrant la daughterboard
- Visser l’ensemble du stack inférieur

# Step 4 : assembler la stack

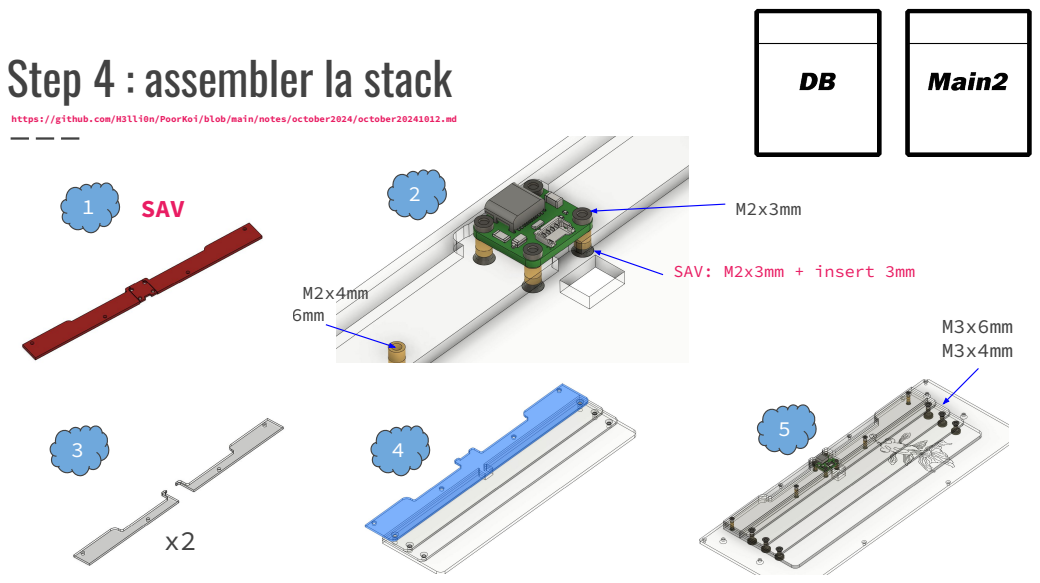
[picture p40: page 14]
SAV: M2x3mm + insert 3mm; SAV

https://github.com/H3lli0n/PoorKoi/blob/main/notes/october2024/october20241012.md

M2x6mm + insert 6mm | M2x4mm

# Step 5 : fixer les pieds

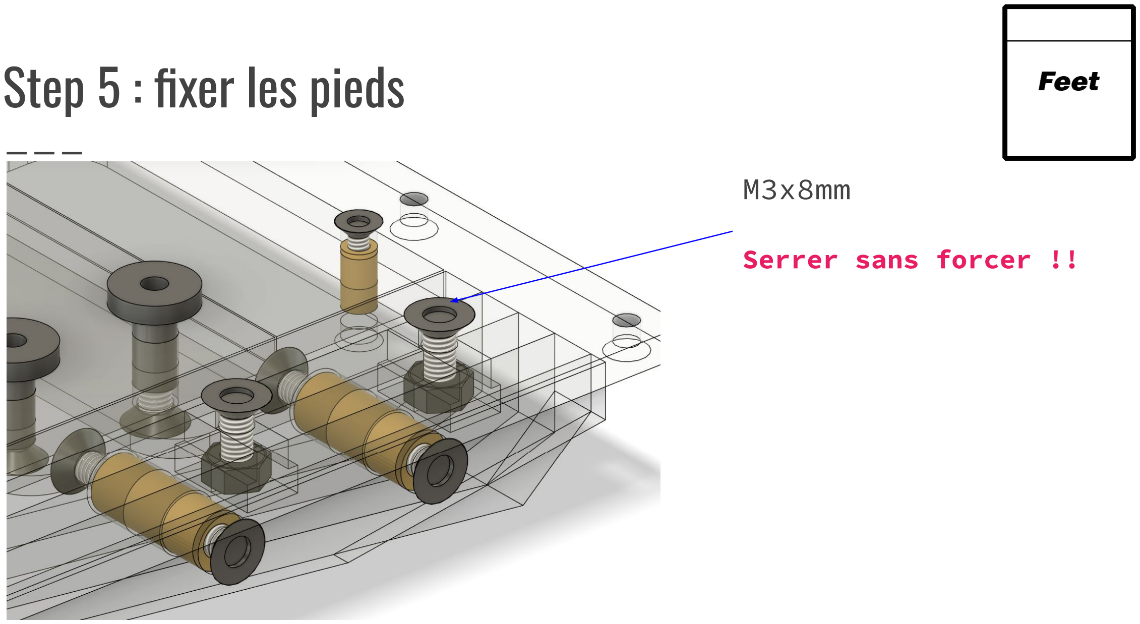
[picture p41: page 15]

## M3x8mm

## Serrer sans forcer !!

# Step 6 : ajouter les gaskets sur la plate

## Les dimensions des gaskets sont : - En haut : 25 mm / 45 mm / 45 mm / 25 mm - En bas : 50mm / 50 mm Collez les gaskets découpés aux dimensions sur les 2 faces de la plate


zone de gasket

## SAV

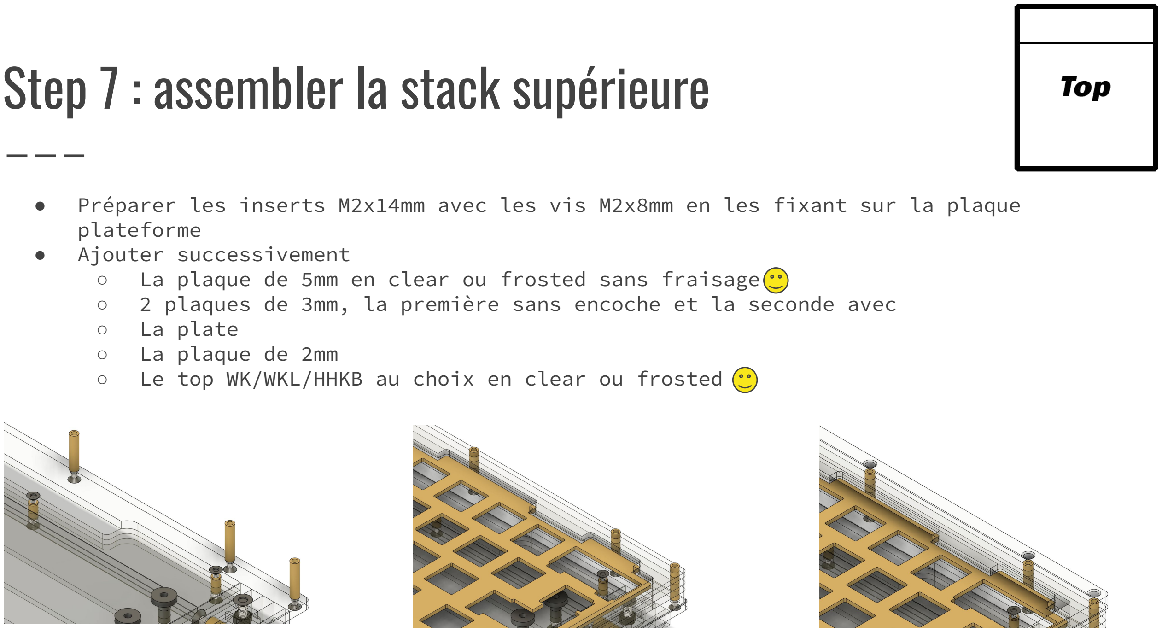
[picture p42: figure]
Step 7 : assembler la stack supérieure; plateforme ● Ajouter successivement; ○ La plate ○ La plaque de 2mm

- Préparer les inserts M2x14mm avec les vis M2x8mm en les fixant sur la plaque
- La plaque de 5mm en clear ou frosted sans fraisage
- 2 plaques de 3mm, la première sans encoche et la seconde avec
- Le top WK/WKL/HHKB au choix en clear ou frosted

# Step 7 : assembler la stack supérieure

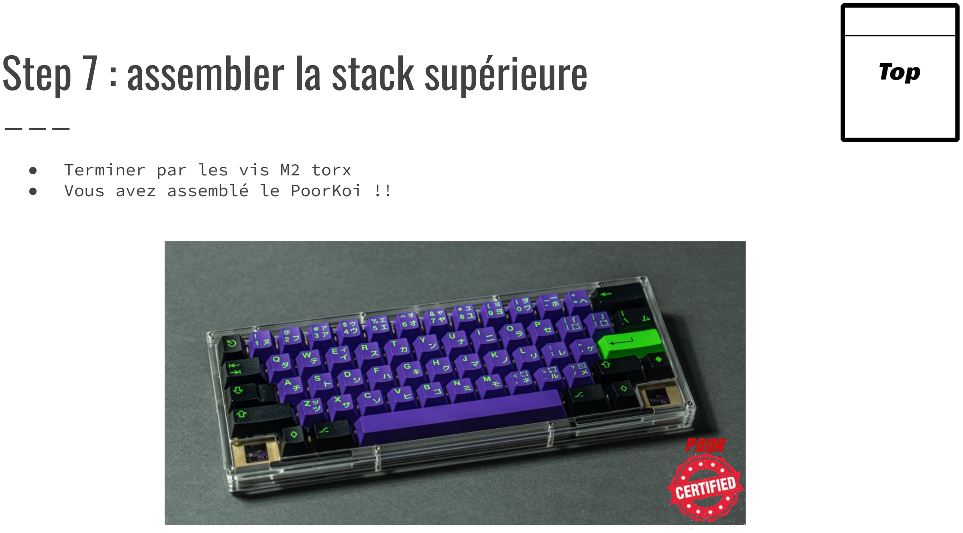
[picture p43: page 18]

- Terminer par les vis M2 torx
- Vous avez assemblé le PoorKoi !!

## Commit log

2024-09-05 fix: led capslock support
2024-09-05 fix: update led
2024-10-02 feat: added plate step file
    [plate.step]
2024-10-07 fix: removed wrong step file
    [plate.step]
2024-10-08 fix: plate and note
    [plate_rev3.step]
